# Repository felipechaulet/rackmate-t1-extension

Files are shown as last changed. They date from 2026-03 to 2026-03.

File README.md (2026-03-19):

# GeekPi RackMate T1 — Corner Post & Beam Extension

OpenSCAD parametric extension parts for the **GeekPi RackMate T1** 10-inch desktop rack. Adds rack-unit height below or between the T1 chassis using printable corner posts and horizontal beams, all locked with dovetail joints and M4 screws.

## Files

| File | What it produces |
|---|---|
| `rackmate_t1_post.scad` | Corner post (print 4 — two left, two right) |
| `rackmate_t1_beam.scad` | Crossbar / horizontal beam connecting two corner posts (print 2)|

---

## Parts overview

### Corner post (`rackmate_t1_post.scad`)

Extends the height of the rack by a configurable number of U (rack units). Each post has:

- A **solid body** that fills one rack-unit height per `ext_U`.
- A three-walled **cradle** at the top that the T1 chassis corners drop into.
- **#10-32 rack holes** on the outer face (EIA-310 spacing: 15.875 mm between pairs, 6.35 mm first-hole offset).
- A **countersunk top hole** that aligns with the T1's bottom mounting point — secured with an M4 countersink screw and nut.
- A **dovetail channel** on the bottom that accepts the crossbar/beam, locked with an M4 countersink screw (see assembly options below).

Print **2** — one with `mirror_post = false` (left), one with `mirror_post = true` (right).

### Crossbar / Beam (`rackmate_t1_beam.scad`)

Runs between two corner posts (front-to-back or left-to-right). Dovetail ends slot into the post channels and are locked with an M4 countersink screw from below. The screw hole is sized to reuse the rubber feet that ship with the RackMate T1 (see assembly options).

Print as many as needed.

---

## Key parameters

### `rackmate_t1_post.scad`

| Parameter | Default | Description |
|---|---|---|
| `ext_U` | `1` | Extension height in rack units |
| `crossbar_span` | `140.0 mm` | Front-to-back distance between post outer faces — **measure your setup** |
| `mirror_post` | `true` | `false` = left post, `true` = right post |
| `t1_screw_z` | `12.5 mm` | Height of the T1 alignment screw above `ext_h` — tune per print |

### `rackmate_t1_beam.scad`

| Parameter | Default | Description |
|---|---|---|
| `pole_length` | `10.0 mm` | Gap between the two post inner faces — **measure your setup** |
| `dovetail_h_left` | `15.0 mm` | Insertion depth into left post |
| `dovetail_h_right` | `15.0 mm` | Insertion depth into right post |
| `pole_height` | `10.0 mm` | Vertical thickness of the pole body |
| `dovetail_height` | `5.0 mm` | Vertical thickness of the dovetail sections |

---

## Hardware BOM

| Qty | Part | Used for |
|---|---|---|
| 2 | M4 countersink screw + nut | Top cradle — attaches post to T1 chassis |
| 2× per beam | M4 countersink screw | Locks beam dovetail into post (see options below) |

**No extra feet needed** — the screw holes at the base are designed to accept the rubber feet and their screws from the RackMate T1.

---

## Print settings

| Setting | Recommendation |
|---|---|
| Material | PLA (or better) |
| Walls / Perimeters | 3 minimum — more for 2U and 3U posts |
| Infill | 25% minimum — increase for taller posts |
| Supports | Not required, but recommended for the dovetail cutout |

---

## Assembly

1. **Print** 2 corner posts (one left, one right) and the required beams/crossbars.
2. **Slide** the beam dovetail ends into the post channels.
3. **Lock** the beam using one of the two options below.
4. **Place** the T1 chassis corners into the top cradle of each post.
5. **Secure** the top with an M4 countersink screw and nut through the cradle hole into the T1's bottom mounting point.

### Beam locking options

The screw holes at the base of each post are sized to fit the rubber feet that ship with the RackMate T1 (M4 screw + rubber foot).

**Option A — reuse T1 rubber feet (recommended)**
Remove the rubber feet from the T1 chassis (they unscrew). Insert the screw up through the beam dovetail into the post, then thread the rubber foot back onto the screw from below. The foot locks the joint and keeps the assembly stable on a desk.

**Option B — standard M4 screw**
Drive a plain M4 countersink screw up through the beam into the post. The T1 rubber feet are not used and can be left on the T1 or set aside.

---

## Compatibility

- Designed for the **GeekPi RackMate T1** 10-inch desktop rack.
- Dovetail channel dimensions (`ch_mouth_w`, `ch_floor_w`, `ch_depth`) are shared between the post and beam files — keep them in sync if you tune the fit.
- Rack holes follow **EIA-310** #10-32 spacing.

## License

[CC BY 4.0](https://creativecommons.org/licenses/by/4.0/) — share and adapt with attribution.

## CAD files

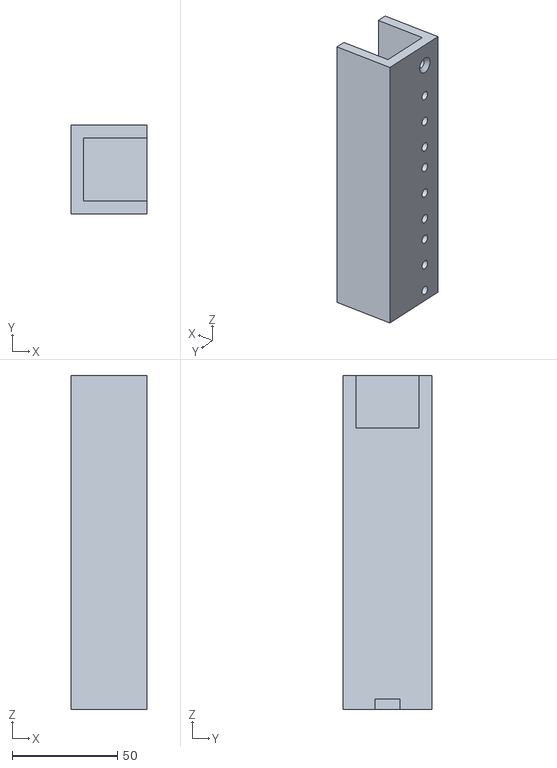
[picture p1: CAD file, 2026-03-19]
rackmate_t1_post_3U_left.stl
36.0 x 42.0 x 158.4

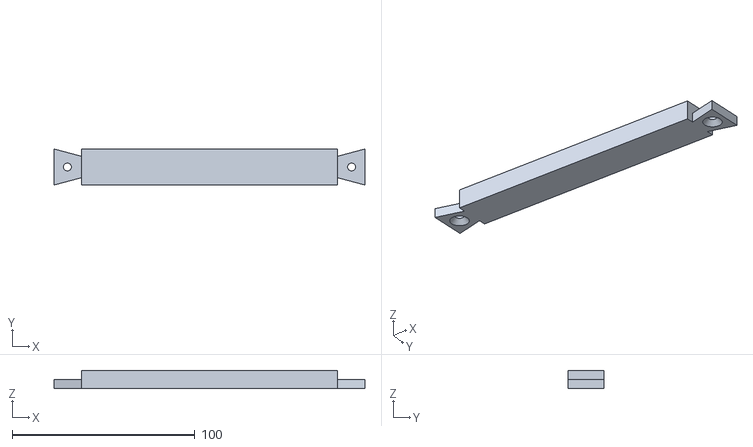
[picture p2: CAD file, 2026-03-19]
rackmate_t1_beam_14cm.stl
170.0 x 19.7 x 10.0

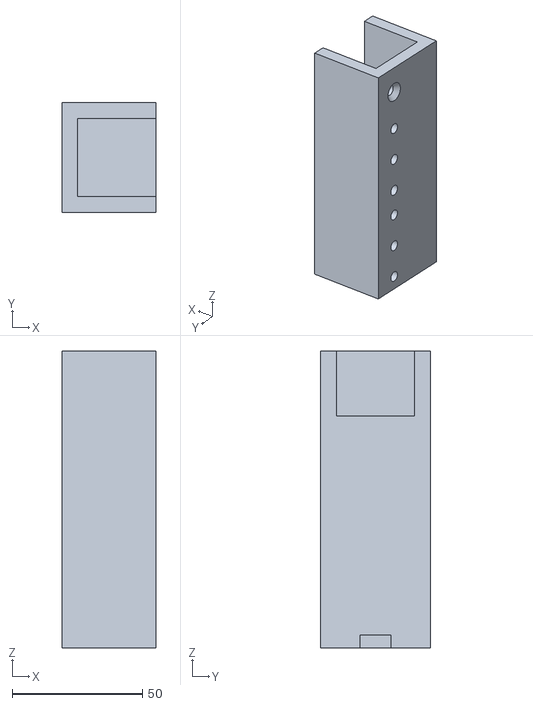
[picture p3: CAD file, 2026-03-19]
rackmate_t1_post_2U_right.stl
36.0 x 42.0 x 113.9

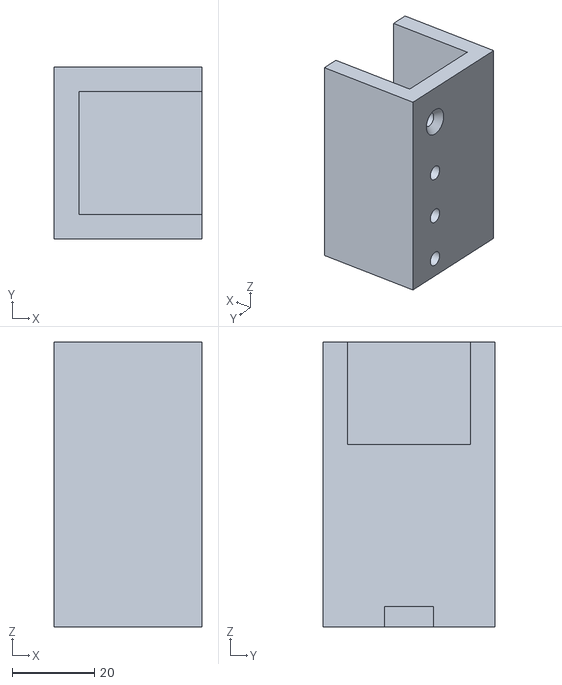
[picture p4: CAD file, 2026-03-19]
rackmate_t1_post_1U_right.stl
36.0 x 42.0 x 69.4

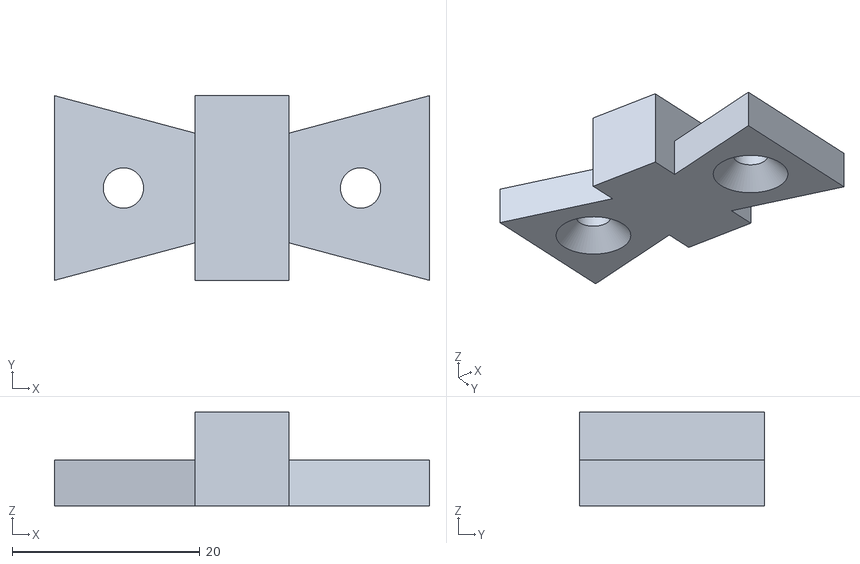
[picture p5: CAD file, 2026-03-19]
rackmate_t1_beam_test.stl
40.0 x 19.7 x 10.0

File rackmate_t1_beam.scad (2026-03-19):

// ============================================================
//  DeskPi RackMate T1 — Horizontal Pole
//  Connects two corner posts horizontally.
//  Dovetail on both ends with countersunk lock screw from bottom.
// ============================================================

/* [★ USER PARAMETERS ★] */
pole_length      = 140.0;  // distance between the two post inner faces (mm) *** MEASURE ***
dovetail_h_left  =  15.0;  // insertion depth of left dovetail into post (mm)
dovetail_h_right =  15.0;  // insertion depth of right dovetail into post (mm)
pole_height      =  10.0;  // vertical thickness of the pole body (mm)
dovetail_height  =  4.9;  // vertical thickness of the dovetail sections (mm)

/* [Lock screw — M4 flat-head, countersunk from bottom] */
lock_d        = 4.3;   // M4 clearance
lock_head_d   = 9.5;   // M4 flat-head diameter
lock_cs_angle = 45;    // half-angle

/* [Dovetail dimensions — must match corner post v9] */
ch_mouth_w   = 12.0;
ch_floor_w   = 20.0;
ch_depth     = 15.0;
ch_clearance =  0.3;

/* [Post reference] */
post_d = 42.0;

$fn = 64;
eps = 0.01;

// ── Derived ──────────────────────────────────────────────────
tm = ch_mouth_w - ch_clearance;
tf = ch_floor_w - ch_clearance;
td = ch_depth   - ch_clearance;
cy = post_d / 2;
total_length = dovetail_h_left + pole_length + dovetail_h_right;

// Lock screw X position: centred in dovetail depth
lock_x_offset = td / 2;  // centred in dovetail depth, matches post receiver hole

// ============================================================
//  MODULE: countersunk hole, oriented along +Z
// ============================================================
module cs_hole(length, hole_d, head_d, cs_angle) {
    cone_h = (head_d/2 - hole_d/2) / tan(cs_angle);
    cylinder(r1=head_d/2, r2=hole_d/2, h=cone_h);
    translate([0, 0, cone_h - eps])
        cylinder(d=hole_d, h=length - cone_h + eps*2);
}

// ============================================================
//  MODULE: single dovetail end
//  Wide at mouth (X=0), narrows to tip (X=depth).
// ============================================================
module dovetail_end(depth) {
    hull() {
        translate([0,         cy - tf/2, 0]) cube([eps, tf, dovetail_height]);
        translate([depth-eps, cy - tm/2, 0]) cube([eps, tm, dovetail_height]);
    }
}

// ============================================================
//  FULL POLE
// ============================================================
difference() {
    union() {
        // Left dovetail
        dovetail_end(dovetail_h_left);

        // Pole body
        translate([dovetail_h_left, cy - tf/2, 0])
            cube([pole_length, tf, pole_height]);

        // Right dovetail
        translate([total_length, 0, 0])
            mirror([1, 0, 0])
                dovetail_end(dovetail_h_right);
    }

    // Lock screw on left dovetail — countersunk from bottom (Z=0)
    translate([lock_x_offset, cy, -eps])
        cs_hole(dovetail_height + eps*2, lock_d, lock_head_d, lock_cs_angle);

    // Lock screw on right dovetail — countersunk from bottom (Z=0)
    translate([total_length - lock_x_offset, cy, -eps])
        cs_hole(dovetail_height + eps*2, lock_d, lock_head_d, lock_cs_angle);
}

// ============================================================
//  PARAMETERS:
//    pole_length      — gap between the two post inner faces (mm)
//    dovetail_h_left  — insertion depth into left post (mm)
//    dovetail_h_right — insertion depth into right post (mm)
//    pole_height      — vertical thickness of pole body (mm)
//    dovetail_height  — vertical thickness of dovetail sections (mm)
//
//  HARDWARE: 2× M3 flat-head screws + nuts (one per dovetail)
//
//  PRINT SETTINGS:
//    PETG or ASA | 4 perimeters | 30% infill
//    Print flat, no supports needed
// ============================================================

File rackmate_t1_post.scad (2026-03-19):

// ============================================================
//  DeskPi RackMate T1 — Corner Post Extension  v9
//  Part 1: corner_post()   — print × 2 (one per side)
//  Part 2: side_crossbar() — print × 2
// ============================================================

/* [★ USER PARAMETERS ★] */
ext_U         = 3;       // rack units of extension height
crossbar_span = 140.0;   // front-to-back between post outer faces *** MEASURE ***
mirror_post   = true;   // false = left post (holes near wall C), true = right post (holes near wall B)

/* [T1 extrusion — measured] */
leg_len       = 30.0;
leg_t         = 10.0;

/* [Cradle walls] */
wall_t        = 6.0;
wall_h        = 25.0;

/* [Rack holes — #10-32] */
one_U        = 44.45;
hole_A       = 15.875;
first_hole   = 6.35;
rack_hole_d  = 4.8;
rack_hole_cx = 12.7;    // hole depth
screw_head_d = 9.0;     // #10-32 flat-head diameter
screw_cs_angle = 41;    // half-angle (82°/2)

/* [Post body] */
post_w = leg_len + wall_t;        // 36 mm  — X: wall_A + T1_leg
post_d = leg_len + wall_t * 2;    // 42 mm  — Y: wall_B + T1_leg + wall_C

/* [Dovetail channel — on inner X face, open toward +X] */
ch_mouth_w   = 12.0;   // width at open face
ch_floor_w   = 20.0;   // width inside (wider = locking)
ch_depth     = 15.0;   // inset depth into post (X direction)
ch_height    = 5.0;    // slot height from base (Z)
ch_clearance = 0.3;    // fit clearance

/* [T1 alignment screw — countersunk hole in cradle wall, aligns with T1 bottom rack hole] */
t1_screw_z    = 12.5;  // distance above ext_h to screw centre (mm) ← TUNE THIS

/* [Crossbar body] */
crossbar_h = 12.0;

/* [M3 crossbar lock screw] */
lock_d        = 3.6;
lock_head_d   = 8.0;
lock_cs_angle = 45;

/* [Rubber feet on crossbar] */
foot_od     = 12.0;
foot_recess = 2.0;

$fn = 64;
eps = 0.01;

// ── Derived ──────────────────────────────────────────────────
ext_h  = ext_U * one_U;

// Rack hole Y position on X face:
//   false (left post)  → near wall C (inner Y) = post_d - wall_t - 5.5
//   true  (right post) → near wall B (outer Y) = wall_t + 5.5
hole_y = mirror_post ? wall_t + 5.5 : post_d - wall_t - 5.5;

function rack_hole_z(u, s) = (u-1)*one_U + first_hole + s*hole_A;

// Top hole = U=ext_U, s=2
top_hole_z = rack_hole_z(ext_U, 2);

// ============================================================
//  MODULE: flat-head countersunk hole (along +X after rotate)
// ============================================================
module cs_hole(length, hole_d, head_d, cs_angle) {
    cone_h = (head_d/2 - hole_d/2) / tan(cs_angle);
    cylinder(r1=head_d/2, r2=hole_d/2, h=cone_h);
    translate([0, 0, cone_h - eps])
        cylinder(d=hole_d, h=length - cone_h + eps*2);
}

// ============================================================
//  MODULE: dovetail channel — inner X face (X=post_w)
//  Narrow at open face, wide inside. ch_height tall at base.
// ============================================================
module channel_cut() {
    hull() {
        translate([post_w - eps, post_d/2 - ch_mouth_w/2, -eps])
            cube([eps, ch_mouth_w, ch_height + eps]);
        translate([post_w - ch_depth, post_d/2 - ch_floor_w/2, -eps])
            cube([eps, ch_floor_w, ch_height + eps]);
    }
}

// ============================================================
//  CORNER POST
// ============================================================
module corner_post() {
    difference() {
        union() {
            // Post body
            cube([post_w, post_d, ext_h]);
            // Wall A — outer X face (X=0)
            translate([0, 0, ext_h])
                cube([wall_t, post_d, wall_h]);
            // Wall B — outer Y face (Y=0)
            translate([0, 0, ext_h])
                cube([post_w, wall_t, wall_h]);
            // Wall C — inner Y face, closes the U
            translate([0, post_d - wall_t, ext_h])
                cube([post_w, wall_t, wall_h]);
        }

        // Dovetail channel on inner X face
        channel_cut();

        // M3 receiver hole in bottom face — centred in dovetail slot (X and Y)
        translate([post_w - ch_depth/2, post_d/2, -eps])
            cylinder(d=lock_d, h=10 + eps);

        // Rack holes on outer X face (X=0) — all plain
        for (u = [1:ext_U]) {
            for (s = [0,1,2]) {
                z = rack_hole_z(u, s);
                translate([-eps, hole_y, z])
                    rotate([0, 90, 0])
                        cylinder(d=rack_hole_d, h=rack_hole_cx + eps);
            }
        }

        // Top countersunk hole — aligns with T1's bottom rack hole
        // Tune t1_screw_z to fine-align with T1
        translate([-eps, hole_y, ext_h + t1_screw_z])
            rotate([0, 90, 0])
                cs_hole(wall_t, rack_hole_d, screw_head_d, screw_cs_angle);
    }
}

// ============================================================
//  SIDE CROSSBAR
// ============================================================
module side_crossbar() {
    tm = ch_mouth_w - ch_clearance;
    tf = ch_floor_w - ch_clearance;
    td = ch_depth   - ch_clearance;
    th = ch_height  - ch_clearance;

    module dovetail_end() {
        hull() {
            translate([post_w - eps, post_d/2 - tm/2, 0])
                cube([eps, tm, th]);
            translate([post_w - td, post_d/2 - tf/2, 0])
                cube([eps, tf, th]);
        }
    }

    difference() {
        union() {
            translate([0, post_d, 0])
                cube([post_w, crossbar_span - 2*post_d, crossbar_h]);
            dovetail_end();
            translate([0, crossbar_span - post_d, 0])
                dovetail_end();
        }

        translate([-eps, post_d/2, crossbar_h/2])
            rotate([0, 90, 0])
                cs_hole(post_w, lock_d, lock_head_d, lock_cs_angle);

        translate([-eps, crossbar_span - post_d/2, crossbar_h/2])
            rotate([0, 90, 0])
                cs_hole(post_w, lock_d, lock_head_d, lock_cs_angle);

        translate([post_w/2, post_d/2, -eps])
            cylinder(d=foot_od, h=foot_recess + eps);
        translate([post_w/2, crossbar_span - post_d/2, -eps])
            cylinder(d=foot_od, h=foot_recess + eps);
    }
}

// ============================================================
//  RENDER
//  Set mirror_post=false for left, mirror_post=true for right
// ============================================================

corner_post();

// Uncomment to preview crossbar:
// translate([50, 0, 0]) side_crossbar();

// ============================================================
//  HARDWARE BOM:
//    2× #10-32 flat-head (82°) — top rack hole countersink screws
//    4× M3 flat-head + nuts    — crossbar lock screws
//    4× rubber stick-on feet Ø12mm — crossbar base ends
//
//  PRINT SETTINGS:
//    PETG or ASA | 6 perimeters | 50% gyroid infill
//    Posts × 2 pairs — upright, no supports
//    Crossbars × 2   — flat, no supports
//
//  ASSEMBLY:
//    1. Slide crossbar dovetail ends UP into post inner-face slots
//    2. Tighten M3 lock screws through post face into dovetail
//    3. Drop T1 corners into cradle from above
//    4. Install rack panels using #10-32 screws (top hole countersunk)
// ============================================================

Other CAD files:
rackmate_t1_post_1U_left.stl
rackmate_t1_post_2U_left.stl
rackmate_t1_post_test.stl
rackmate_t1_post_3U_right.stl

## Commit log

2026-03-19 Added first working version
    [rackmate_t1_beam.scad, rackmate_t1_post.scad]
2026-03-19 Update README with correct assembly instructions and add STL exports
    - Fix BOM: M3 heated insert + M3 screw (bottom dovetail), M4 countersink + nut (top/T1)
    - Rubber feet noted as optional; felt pads listed as alternative
    - Correct file descriptions: post.scad is post only, beam.scad is crossbar/beam
    - Update print settings: PLA, 3+ walls, 25% infill, supports for dovetail cutout
    - Rewrite assembly steps to match actual build sequence
    - Tune parameters: pole_length 140 mm, ext_U 3, dovetail_height 4.9, lock_d 4.5
    - Add pre-exported STL files for 1U/2U/3U posts and 14 cm beam
    [rackmate_t1_beam.scad, rackmate_t1_beam_14cm.stl, rackmate_t1_post.scad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]
2026-03-19 Update README.md
    Updated number of prints per part
2026-03-19 Redesign bottom joint to reuse T1 rubber feet; update README
    Screw holes at the base of each post are now M4-sized, matching the
    rubber feet that ship with the RackMate T1. Users can either remove the
    rubber feet from the T1 and reuse them to lock the beam (Option A), or
    use a plain M4 countersink screw (Option B). README updated with both
    assembly options and corrected BOM.
    [rackmate_t1_beam.scad, rackmate_t1_beam_14cm.stl, rackmate_t1_beam_test.stl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]
